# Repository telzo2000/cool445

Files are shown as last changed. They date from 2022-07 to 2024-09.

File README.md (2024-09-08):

# cool445
## What is cool445？

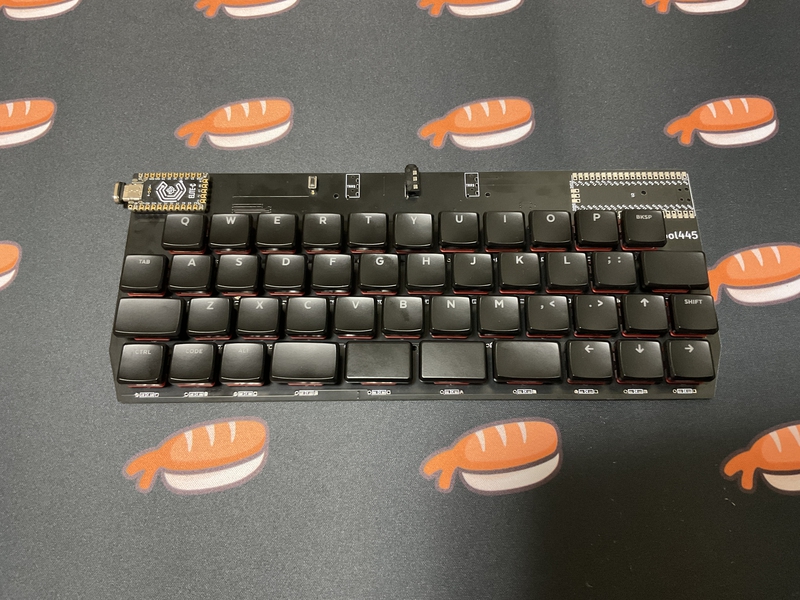
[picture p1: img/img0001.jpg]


cool445 is a 45-key keyboard.
<br>
The key layout is row staggered.
<br><br>
coo445は45キーのキーボードです。
<br>
キーレイアウトは、ロウスタッガードです。
<br><br>
You can choose either pro micro or raspberry pi pico to use.
<br><br>
pro microかraspberry pi picoのどちらか一つを選んで使うことができます。
<br><br>
You can choose either choc switch or cherry mx switch to use.
<br><br>
Chocスイッチか CHERRY MXスイッチのどちらか一つを選んで使うことができます。
<br>
<br>
It can be connected to cool450 with a TRRS cable.
<br>
By connecting, cool445 can use the numeric keypad macro pad.
<br>
You can put the cool640 on the left or right side of the cool445.
<br><br>
cool450とTRRSケーブルで繋ぐことができます。
<br>
繋ぐことにより、cool445はテンキーマクロパッドを使うことができます。
<br>
cool445の左右好きな方に、cool640を置くことができます。

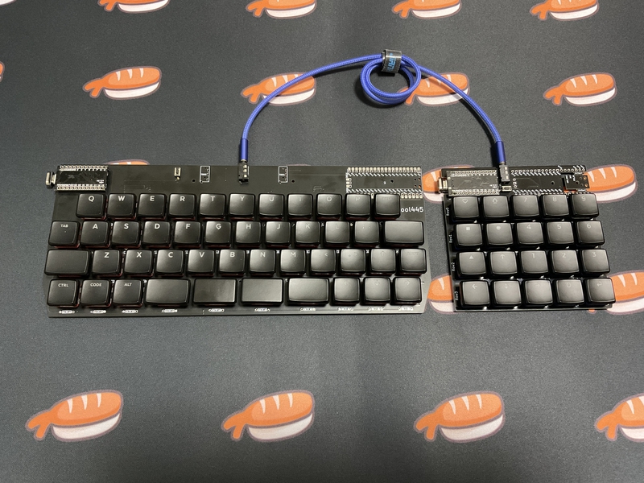
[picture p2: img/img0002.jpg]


<br>
<br>
It will be distributed on booth in the future, but you can freely use the data here and place an order with the PCB manufacturer.
<br><br>
将来、boothにて頒布しますが、ここにあるデータを自由に使い、各自がPCB製造元に発注しても構いません。
<br><br>
I do not take any responsibility for the data that you freely use.
<br>
Please use at your own risk.
<br><br>
各自が自由に使ったデータについては、私は一切の責任を負いません。
<br>
自己責任で利用してください。
<br>

## Build Guide
https://github.com/telzo2000/cool445/blob/main/buildguide_for_cool445.md

<br>

## Firmware
PRK_FIRMWARE
https://github.com/telzo2000/cool445/tree/main/PRK_FIRMWARE

QMK_FIRMWARE
https://github.com/telzo2000/cool445/tree/main/QMK_fimware

remap
https://remap-keys.app/

vial
https://get.vial.today/

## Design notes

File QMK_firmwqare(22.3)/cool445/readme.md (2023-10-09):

# cool445

cool445

*A short description of the keyboard/project*

* Keyboard Maintainer: [m.ki](https://github.com/telzo2000)
* Hardware Supported: *The PCBs, controllers supported*
* Hardware Availability: *Links to where you can find this hardware*

Make example for this keyboard (after setting up your build environment):

    make cool445:default

Flashing example for this keyboard:

    make cool445:default:flash

See the [build environment setup](https://docs.qmk.fm/#/getting_started_build_tools) and the [make instructions](https://docs.qmk.fm/#/getting_started_make_guide) for more information. Brand new to QMK? Start with our [Complete Newbs Guide](https://docs.qmk.fm/#/newbs).

## Bootloader

Enter the bootloader in 3 ways:

* **Bootmagic reset**: Hold down the key at (0,0) in the matrix (usually the top left key or Escape) and plug in the keyboard
* **Physical reset button**: Briefly press the button on the back of the PCB - some may have pads you must short instead
* **Keycode in layout**: Press the key mapped to `QK_BOOT` if it is available

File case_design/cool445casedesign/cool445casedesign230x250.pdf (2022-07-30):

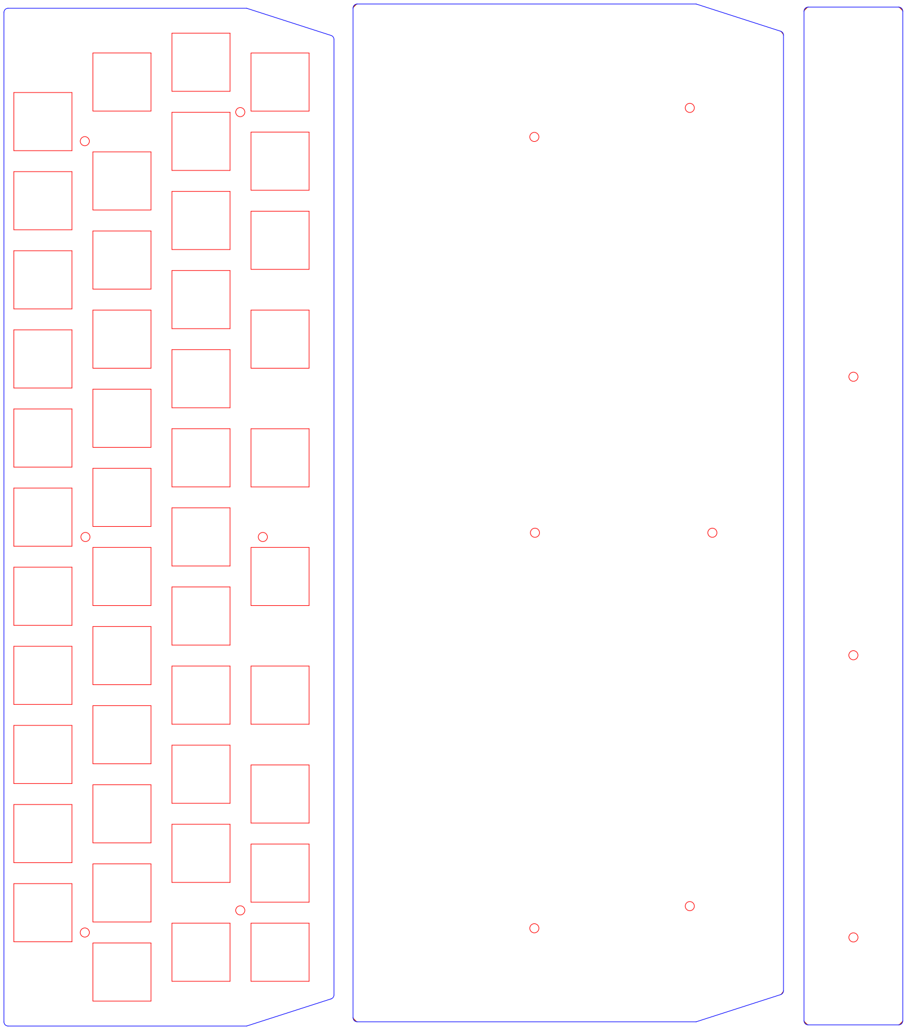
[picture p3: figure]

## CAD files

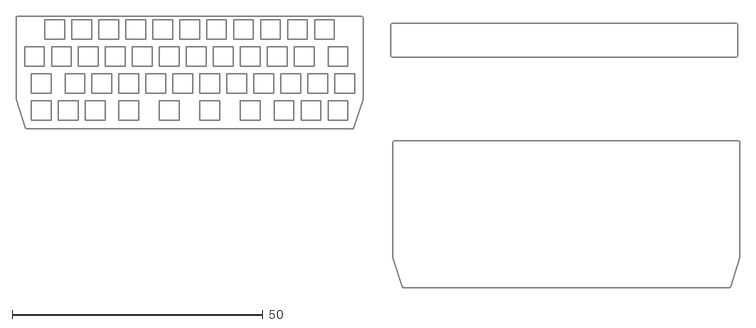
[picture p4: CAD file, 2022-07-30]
case_design/cool445casedesign/cool445casedesign230x250.dxf
144.2 x 54.1

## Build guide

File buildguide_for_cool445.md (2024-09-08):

# Build guide

## Parts list

| No. | Patrs | Quantity | remarks | Suppliers | Cost |
|--|--|--|--|--|--|
|番号|名前|数|備考|調達先|参考価格（送料込）|<br>
|1|PCB|1|40%keyboard<br>keyboard|[elecrow](https://www.elecrow.com)<br>[JLCPCB](https://jlcpcb.com)<br>[ALLPCB](https://www.allpcb.com)|５枚で30〜40ドル|<br>
|2-1|Switch Plate<br>スイッチプレート|１||[工房Emerge+](https://www.emergeplus.jp/laser-cutting-service/contact/)<br>[遊舎工房](https://yushakobo.jp)<br>[elecrow](https://www.elecrow.com)|種類による。|
|2-2|Cover Plate<br>カバープレート|１|↑|↑|↑|
|2-3|Bottom Plate<br>ボトムプレート|１|↑|↑|↑|
|3|M2screw<br>M2ネジ|6|4mm<br>CoverPlateで使用|DIYショップなど|10本で100円程度|
|4|M2screw<br>M2ネジ|6|3mm|↑|↑|
|5A|M2screw<br>M2ネジ|6|8mm<br>MXスイッチ使用時|↑|↑|
|5B|M2screw<br>M2ネジ|6|6mm<br>chocスッチ使用時|↑|↑|
|6A|M2spacer<br>M2スペーサー|12|3mmメス-メス<br>MXスイッチ使用時|[ヒロスギネット](https://www.hirosugi-net.co.jp/shop/c/c10/)<br>[遊舎工房](https://yushakobo.jp)|20本で800円程度|
|6B|M2spacer<br>M2スペーサー|6|3mmメス-メス<br>chocスイッチ使用時|[ヒロスギネット](https://www.hirosugi-net.co.jp/shop/c/c10/)<br>[遊舎工房](https://yushakobo.jp)|20本で800円程度|
|7|M2spacer<br>M2スペーサー|3|6mmメス-メス<br>CoverPlateで使用|[ヒロスギネット](https://www.hirosugi-net.co.jp/shop/c/c10/)<br>[遊舎工房](https://yushakobo.jp)|20本で800円程度|
|8|pro micro|1|ピンヘッダも別途購入|[遊舎工房](https://yushakobo.jp)<br>[Talp Keyboard](https://talpkeyboard.net)<br>[Daily Craft Keyboard](https://shop.dailycraft.jp)等|価格変動中|
||Raspberry Pi Pico|1|ピンヘッダも別途購入|[遊舎工房](https://yushakobo.jp)等|１個550円|
|9A|Swith socket<br>スイッチソケット|45|cherry MX互換|[遊舎工房](https://yushakobo.jp)<br>[Talp Keyboard](https://talpkeyboard.net)<br>[Daily Craft Keyboard](https://shop.dailycraft.jp)等|10個で165円程度|
|9B|Swith socket<br>スイッチソケット|45|choc互換|[遊舎工房](https://yushakobo.jp)<br>[Talp Keyboard](https://talpkeyboard.net)<br>[Daily Craft Keyboard](https://shop.dailycraft.jp)等|10個で165円程度|
|10|Diode<br>ダイオード|45|リードタイプでもSMDでも可|[遊舎工房](https://yushakobo.jp)<br>[Talp Keyboard](https://talpkeyboard.net)<br>[Daily Craft Keyboard](https://shop.dailycraft.jp)等|100個で220円程度から|
|11|タクトスイッチ|1|２本足のもの|[遊舎工房](https://yushakobo.jp)<br>[Talp Keyboard](https://talpkeyboard.net)<br>[Daily Craft Keyboard](https://shop.dailycraft.jp)等|１個11円程度|
|12|TRRSジャック|1|MJ-4PP-9|[遊舎工房](https://yushakobo.jp)<br>[Talp Keyboard](https://talpkeyboard.net)<br>[Daily Craft Keyboard](https://shop.dailycraft.jp)等|１個55円|

この他に、TRRSケーブル、USBケーブル、キーキャップ等が必要です。

## Firmware

### 1 PRK_FIRMWARE

[Here](https://github.com/telzo2000/cool445/tree/main/PRK_FIRMWARE)

<br>

### 2 QMK_FIRMWARE

参考<br>

https://github.com/telzo2000/Hello_keyboard/blob/main/readme_about_firmware.md

<br>

[Here](https://github.com/telzo2000/cool445/tree/main/QMK_fimware)

<br>

[remap](https://remap-keys.app/)

<br>

## Build 1(PCB only)

### 1 Parts check

Front side（表面）
<br>
Cool445 is written on the upper right of the PCB.
<br>
PCB右上にcool445と書かれています。
<br>

Back side（裏面）

![]()

### 2 Diode soldering

Solder the diode on the back side.
<br>
裏面にダイオードのハンダ付けをします。
<br>

There are lead type and SMD diodes.
<br>
ダイオードはリードタイプか、SMDがあります。
<br>
Here, we will explain the lead type soldering.
<br>
ここでは、リードタイプのハンダ付けの説明をします。
<br>
However, those who adopt the choc switch should use SMD diodes.
<br>
ただし、chocスイッチを採用する人は、SMDのダイオードを使用してください。
<br>

Use a lead bender to bend the legs of the diode.
<br>
リードベンダーを使い、ダイオードの足を曲げます。
<br>

Insert the diode into the board.
<br>
ダイオードを基板に挿しこみます。
<br>

Please pay attention to the orientation of the diode.
<br>
ダイオードの向きに注意してください。
<br>

Secure the diode with masking tape, then face up.
<br>
マスキングテープでダイオードを固定してから、表面を上にします。
<br>
Solder the protruding legs.
<br>
はみ出ている足部分に、ハンダ付けをします。
<br>
After soldering, use nippers to cut off the protruding legs.
<br>
はんだ付けが終わったら、はみ出ている足をニッパーで切り取ってください。
<br>

[８倍速　Diodeハンダ付け動画](https://youtu.be/Yaodh2-XxV4)

<br>
<br>

### 3 Soldering switch sockets

Solder the switch sockets on the back side.
<br>
裏面にスイッチソケットのハンダ付けをします。
<br>
cool445 is compatible with both choc and cherry MX switches.
<br>
cool445はchocスイッチとcherryMXスイッチの両方に対応しています。
<br>
Both can be installed.
<br>
両方を取り付けることが可能です。
<br>
Here, solder the cherryMX switch.
<br>
ここでは、cherryMXスイッチのハンダ付けを行います。
<br>
Place the switch socket so that the letters MX are hidden.
<br>
MXという文字が隠れるように、スイッチソケットを乗せてください。
<br>
That is the correct switch socket orientation.
<br>
それが正しいスイッチソケットの向きになります。
<br>
When using a choc switch, place the switch socket so that the letters choc are hidden.
<br>
chocスイッチの時は、chocという文字が隠れるように、スイッチソケットを乗せてください。
<br>

Apply solder to both pads.
<br>
両方のパッドにハンダを盛ります。
<br>
Place the switch socket and fix it with a warm soldering iron while melting the solder.
<br>
スイッチソケットを乗せて、温めたハンダゴテで、ハンダを溶かしながら、固定します。
<br>
You can make it easier by working while holding it with tweezers.
<br>
ピンセットで押さえながら、作業をすると楽にできます。
<br>

[８倍速　Switch socketハンダ付け動画](https://youtu.be/E__mHvmIXQo)

<br><br>

### 4 Soldering reset switch & TRRS jack 

Insert the reset switch on the surface.
<br>
表面にリセットスイッチを挿しこみます。
<br>
Solder the legs of the reset switch from the back.
<br>
裏面からリセットスイッチの足をハンダ付けします。
<br>
Solder the TRRS jack in the same way near the reset switch.
<br>
TRRSジャックは、リセットスイッチの近くに同じようにハンダ付けします。
<br>
There are 3 TRRS jacks. Please choose one and use it.
<br>
TRRSジャックは3箇所あります。どれか一つを選んで使ってください。
<br>

[８倍速　Reset switch,TRRS jackハンダ付け動画](https://youtu.be/3gEbExaOAv4)

<br><br>

### 5　Choice of Pro micro or Raspberry Pi Pico

You can run cool640 in either Pro micro or Raspberry Pi Pico.
<br>
cool445をpro microかラズパイピコのどちらか一方で動作させることができます。
<br>
＜case 1＞
<br>
When you choose Pro micro, place it on the left side of the TRRS jack.
<br>
pro microを選んだ時、TRRSジャックの左側にpro microを取り付けてください。
<br>

Use the conthrough to fix the pro micro with the side with the parts facing down.
<br>
pro microの部品のある面を下向きに、コンスルーを使い、固定してください。
<br>

Pay attention to the orientation of the conthrough.
<br>
コンスルーの向きに注意してください。
<br>

＜case 2＞
<br>
When you choose Raspberry Pi Pico, place it on the right side of the TRRS jack.
<br>
ラズパイピコを選んだ時、TRRSジャックの右側にラズパイピコを取り付けてください。
<br>
Place the side of the Raspberry Pi Pico with the parts facing up, and fix it using the connector.
<br>
ラズパイピコの部品のある面を下向きに、コンスルーを使い、固定してください。
<br>

<br>
Pay attention to the orientation of the conthrough.
<br>
コンスルーの向きに注意してください。
<br>

<br>

### 6　Test

Please write the firmware and check the operation.
<br>
ファームウェアを書き込んで、動作確認をしてください。
<br>

Install a switch or measure continuity with tweezers, etc.
<br>
スイッチを取り付けるか、ピンセット等で導通をはかるかを行います。
<br>

### PRK_FIRMWARE

[Here](https://github.com/telzo2000/cool445/tree/main/PRK_FIRMWARE)

<br>

### QMK_FIRMWARE
[Here]([https://github.com/telzo2000/cool640/tree/main/firmware](https://github.com/telzo2000/cool445/tree/main/QMK_fimware)

<br>
[remap](https://remap-keys.app/)
<br>
<br>

### 7 Installation of key switch

Attach your favorite key switch.
<br>
好きなキースイッチを取り付けてください。
<br>

<br>
If you like, attach a rubber cushion to the back and you're done.
<br>
お好みで裏面にラバークッションを取り付けたら、完成です。
<br>
<br>
<br>

## Build 2(Acrylic sandwich mount case)



After 1 ~ 6 of build1, please do the next step.
<br>
build1の1~6の後、次の工程をしてください。
<br>

### 1 Installation of cover plate

Prepare a cover plate, M2 spacer 6mm（x３）, and M2 screw 4mm（x６）.
<br>
カバープレート、M2スペーサー6mm（３個）、M2ネジ3mm（６本）を用意します。
<br>
Screw the spacer to the cover plate in the same orientation.
<br>
カバープレートに同じ向きで、スペーサーをネジで固定します。
<br>
Then use the remaining screws to attach the cover plate to the PCB.
<br>
次に、残りのネジを使い、カバープレートをPCBに取り付けます。
<br>
There is an orientation of the cover plate, so it is good to check it once before starting work.
<br>
カバープレートの向きがあり、作業前に一度、重ねて確認すると良いです。
<br>
<br>

### 2-1 Installation of switch plate（choc switch）

Prepare a switch plate, M2 spacer 3 mm（x６）, and M2 screw 6 mm（x６）.
<br>
スイッチプレート、M2スペーサー３mm（６本）、M2ネジ６mm（６本）を用意します。
<br>
Fix the screws in 6 places.
<br>
ネジを６箇所、固定します。
<br>
Insert the screws in the order of the switch plate and the PCB, and fix them with spacers on the back of the PCB.
<br>
ネジはスイッチプレート、PCBの順でさしこみ、PCBの裏面でスペーサーで固定します。
<br>

<br>

### 2-2 Installation of switch plate（cherry MX switch）

Prepare a switch plate, M2 spacer 3 mm（x１２）, and M2 screw 8 mm（x６）.
<br>
スイッチプレート、M2スペーサー３mm（１２本）、M2ネジ８mm（６本）を用意します。
<br>
Fix the screws in 6 places.
<br>
ネジを６箇所、固定します。
<br>
Insert the switch plate into the screw and fix it with a spacer.
<br>
ネジはスイッチプレートをさしこみ、スペーサーで固定します。
<br>
Next, insert the switch plate into the PCB and secure it with a spacer on the back of the PCB.
<br>
次に、スイッチプレートをPCBにさしこみ、PCBの裏面でスペーサーで固定します。
<br>

### 3 Installation of bottom plate 

Prepare the bottom plate and M2 ３mm screws（x６）.
<br>
ボトムプレート、M２ネジ３mm（６本）を用意します。
<br>
Place the bottom plate according to the spacer on the back of the PCB and fix it with screws.
<br>
PCB裏面にあるスペーサーに合わせて、ボトムプレートをのせて、ネジで固定します。
<br>
<br>
From here, proceed with step 7 of build1.
<br>
ここからは、build１の７の工程を進めてください。
<br>

Have a fun selfmade keyboard life!
<br>
楽しい自作キーボード生活を!

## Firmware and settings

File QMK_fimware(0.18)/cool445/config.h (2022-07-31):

// Copyright 2022 m.ki (@telzo2000)
// SPDX-License-Identifier: GPL-2.0-or-later

#pragma once

#include "config_common.h"

/* USB Device descriptor parameter */
#define VENDOR_ID    0x4D43
#define PRODUCT_ID   0x0445
#define DEVICE_VER   0x0001
#define MANUFACTURER telzo2000
#define PRODUCT      cool445

/* key matrix size */
#define MATRIX_ROWS 8
#define MATRIX_COLS 12

/*
 * Keyboard Matrix Assignments
 *
 * Change this to how you wired your keyboard
 * COLS: AVR pins used for columns, left to right
 * ROWS: AVR pins used for rows, top to bottom
 * DIODE_DIRECTION: COL2ROW = COL = Anode (+), ROW = Cathode (-, marked on diode)
 *                  ROW2COL = ROW = Anode (+), COL = Cathode (-, marked on diode)
 *
 */
#define MATRIX_ROW_PINS { B5, B4, B1, F7 }
#define MATRIX_COL_PINS { F5, F6, B3, B6, B2, D1, D0, D4, C6, D7, E6, F4  }
#define UNUSED_PINS

/* COL2ROW, ROW2COL */
#define DIODE_DIRECTION ROW2COL

/*
 * Split Keyboard specific options, make sure you have 'SPLIT_KEYBOARD = yes' in your rules.mk, and define SOFT_SERIAL_PIN.
 */
#define SOFT_SERIAL_PIN D2  // or D1, D2, D3, E6

//#define LED_NUM_LOCK_PIN B0
//#define LED_CAPS_LOCK_PIN B1
//#define LED_SCROLL_LOCK_PIN B2
//#define LED_COMPOSE_PIN B3
//#define LED_KANA_PIN B4

//#define BACKLIGHT_PIN B7
//#define BACKLIGHT_LEVELS 3
//#define BACKLIGHT_BREATHING

#define RGB_DI_PIN D3
#ifdef RGB_DI_PIN
#    define RGBLED_NUM 16
#    define RGBLIGHT_HUE_STEP 8
#    define RGBLIGHT_SAT_STEP 8
#    define RGBLIGHT_VAL_STEP 8
#    define RGBLIGHT_LIMIT_VAL 255 /* The maximum brightness level */
#    define RGBLIGHT_SLEEP  /* If defined, the RGB lighting will be switched off when the host goes to sleep */
/*== all animations enable ==*/
#    define RGBLIGHT_ANIMATIONS
/*== or choose animations ==*/
#    define RGBLIGHT_EFFECT_BREATHING
#    define RGBLIGHT_EFFECT_RAINBOW_MOOD
#    define RGBLIGHT_EFFECT_RAINBOW_SWIRL
#    define RGBLIGHT_EFFECT_SNAKE
#    define RGBLIGHT_EFFECT_KNIGHT
#    define RGBLIGHT_EFFECT_CHRISTMAS
#    define RGBLIGHT_EFFECT_STATIC_GRADIENT
#    define RGBLIGHT_EFFECT_RGB_TEST
#    define RGBLIGHT_EFFECT_ALTERNATING
/*== customize breathing effect ==*/
/*==== (DEFAULT) use fixed table instead of exp() and sin() ====*/
#    define RGBLIGHT_BREATHE_TABLE_SIZE 256      // 256(default) or 128 or 64
/*==== use exp() and sin() ====*/
#    define RGBLIGHT_EFFECT_BREATHE_CENTER 1.85  // 1 to 2.7
#    define RGBLIGHT_EFFECT_BREATHE_MAX    255   // 0 to 255
#endif

/* Debounce reduces chatter (unintended double-presses) - set 0 if debouncing is not needed */
#define DEBOUNCE 5

/* define if matrix has ghost (lacks anti-ghosting diodes) */
//#define MATRIX_HAS_GHOST

/* Mechanical locking support. Use KC_LCAP, KC_LNUM or KC_LSCR instead in keymap */
#define LOCKING_SUPPORT_ENABLE
/* Locking resynchronize hack */
#define LOCKING_RESYNC_ENABLE

/* If defined, GRAVE_ESC will always act as ESC when CTRL is held.
 * This is useful for the Windows task manager shortcut (ctrl+shift+esc).
 */
//#define GRAVE_ESC_CTRL_OVERRIDE

/*
 * Force NKRO
 *
 * Force NKRO (nKey Rollover) to be enabled by default, regardless of the saved
 * state in the bootmagic EEPROM settings. (Note that NKRO must be enabled in the
 * makefile for this to work.)
 *
 * If forced on, NKRO can be disabled via magic key (default = LShift+RShift+N)
 * until the next keyboard reset.
 *
 * NKRO may prevent your keystrokes from being detected in the BIOS, but it is
 * fully operational during normal computer usage.
 *
 * For a less heavy-handed approach, enable NKRO via magic key (LShift+RShift+N)
 * or via bootmagic (hold SPACE+N while plugging in the keyboard). Once set by
 * bootmagic, NKRO mode will always be enabled until it is toggled again during a
 * power-up.
 *
 */
//#define FORCE_NKRO

/*
 * Feature disable options
 *  These options are also useful to firmware size reduction.
 */

/* disable debug print */
//#define NO_DEBUG

/* disable print */
//#define NO_PRINT

/* disable action features */
//#define NO_ACTION_LAYER
//#define NO_ACTION_TAPPING
//#define NO_ACTION_ONESHOT

/* disable these deprecated features by default */
#define NO_ACTION_MACRO
#define NO_ACTION_FUNCTION

/* Bootmagic Lite key configuration */
//#define BOOTMAGIC_LITE_ROW 0
//#define BOOTMAGIC_LITE_COLUMN 0
